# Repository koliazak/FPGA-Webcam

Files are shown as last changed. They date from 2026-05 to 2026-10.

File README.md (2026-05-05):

# Zynq-7010 Vision



This repository contains the source code, hardware design, and documentation for an edge computer vision project based on the Xilinx Zynq-7010 SoC (EBAZ4205 board). 

The goal of this project is to build a hardware-accelerated **Stereo Camera System** capable of capturing frames, detecting objects, and estimating depth. The project is divided into phases, starting with a single-camera streaming pipeline and scaling up to dual-camera stereo vision.

## Technical Specification & Project Roadmap

The development is divided into three main phases to ensure iterative progress of the Hardware/Software (HW/SW) partitioning.

### Phase 1: Minimum Viable Product (Capture & Web Streaming)

- **Goal:** Establish a reliable image capture pipeline and stream the video to a web interface.
- **Tasks:**
  - Implement mowdule in PL (FPGA) to configure the OV7670 registers.
  - Develop a pixel capture module to receive parallel data from the camera and convert it to an AXI-Stream.
  - Use DMA to write frames to DDR memory.
  - Implement a lightweight web server on the PS (ARM processor) running Petalinux to stream the frames.

### Phase 2: Hardware-Accelerated Image Processing
- **Goal:** Offload image basic computer vision tasks to the FPGA fabric.
- **Features to implement:**
  * Image enhancement (brightness/contrast adjustment, color space conversion).
  * Video stabilization.
  * Background removal / masking.
  * Basic face tracking using hardware-accelerated algorithms.

### Phase 3: Stereo Vision & Depth Estimation
- **Goal:** Synchronous capture from two cameras to calculate object distance.

## Hardware/Software Partitioning (Co-Design)

One of the core research aspects of this project is determining the optimal boundary between Programmable Logic (PL) and the Processing System (PS). 

- **Programmable Logic (FPGA):** Will handle deterministic, high-throughput operations (data ingestion, AXI-Stream conversions, low-level image processing, edge detection).
- **Processing System (ARM Core):** Will handle high-level application logic, web server, and complex CV inferences that are too heavy for the chip's logic fabric.

*(Note: The exact partitioning will be updated as experiments are conducted and performance bottlenecks are analyzed).*

## Tools & Technologies
- **HDL:** SystemVerilog / Verilog
- **Synthesis & Implementation:** Xilinx Vivado
- **Hardware:**
  - EBAZ4205 board
  - extension board 
  - 2x OV7670 camera module without FIFO

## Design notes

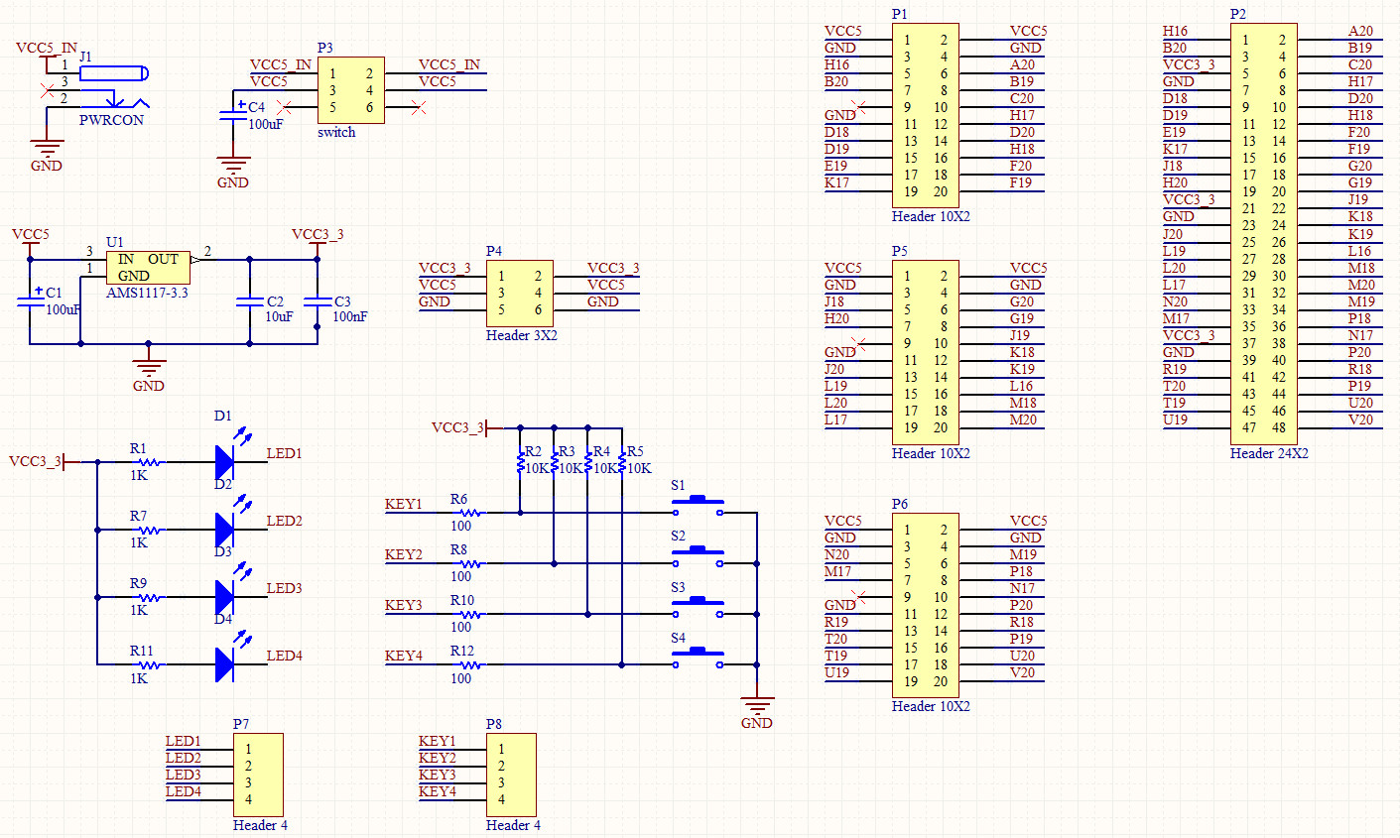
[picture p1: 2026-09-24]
docs/extension-board.jpg

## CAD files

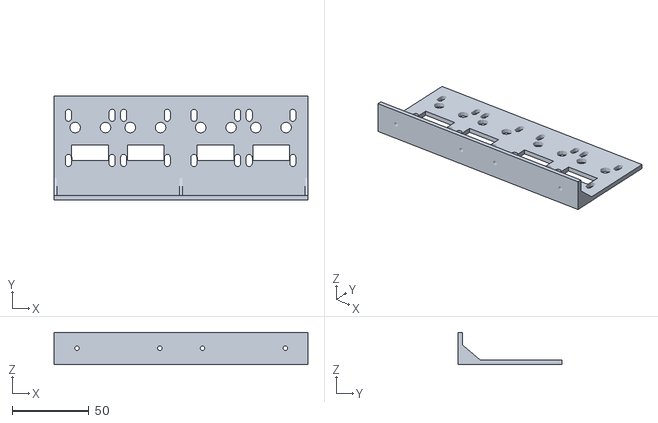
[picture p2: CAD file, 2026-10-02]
docs/CameraHolder.stl
165.9 x 68.0 x 20.9

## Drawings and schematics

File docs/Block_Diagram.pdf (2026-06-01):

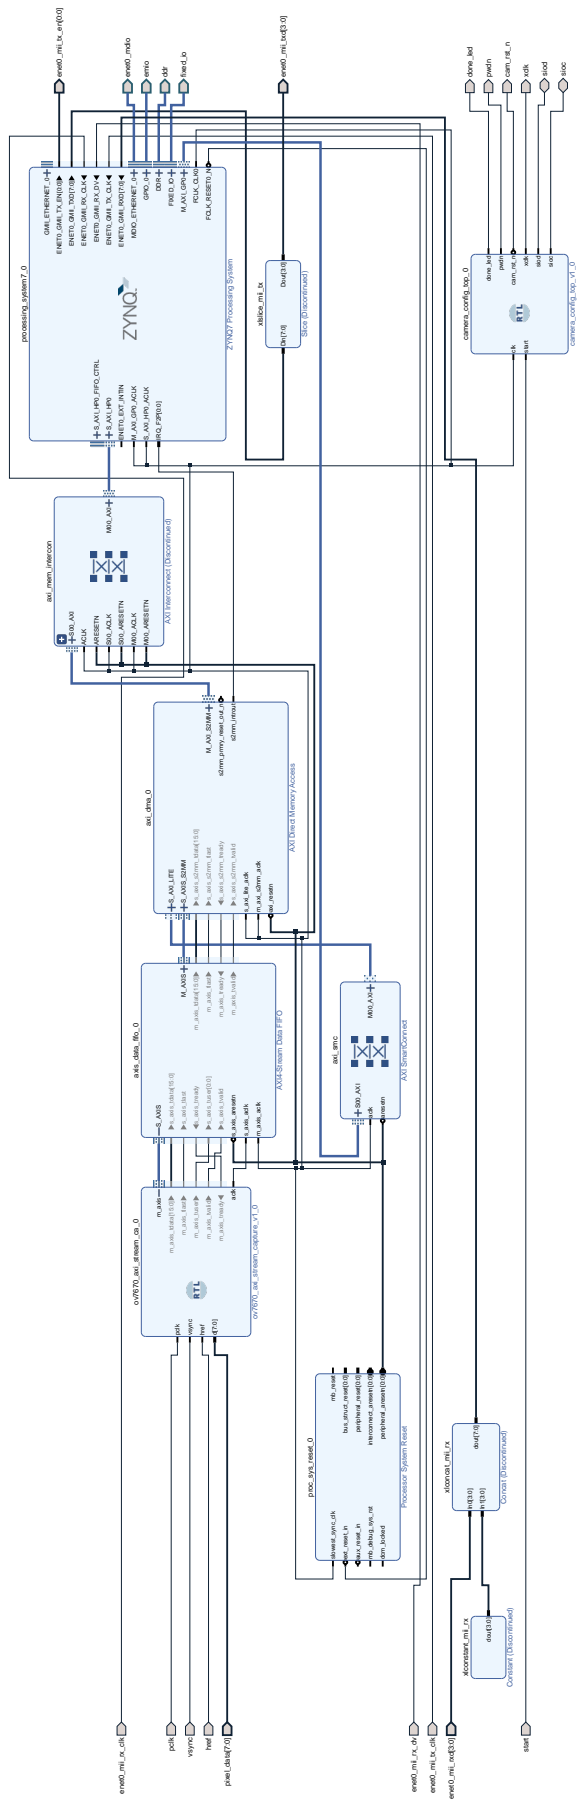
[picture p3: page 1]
axi_dma_0; S_AXI_LITE; M_AXI_S2MM; S_AXIS_S2MM; s_axis_s2mm_tdata[15:0]; s_axis_s2mm_tlast; s_axis_s2mm_tready; s_axis_s2mm_tvalid; s_axi_lite_aclk m_axi_s2mm_aclk; axi_resetn; s2mm_prmry_reset_out_n; s2mm_introut; axi_mem_intercon; S00_AXI; M00_AXI; ACLK; ARESETN; S00_ACLK; S00_ARESETN M00_ACLK M00_ARESETN; axi_smc; AXI SmartConnect; S00_AXI M00_AXI aclk; aresetn; axis_data_fifo_0; S_AXIS; s_axis_tdata[15:0]; s_axis_tlast; s_axis_tready; s_axis_tuser[0:0]; s_axis_tvalid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

AXI Interconnect (Discontinued)

AXI Direct Memory Access

AXI4-Stream Data FIFO

Processor System Reset

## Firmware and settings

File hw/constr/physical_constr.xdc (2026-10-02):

######################################################################
#                                                                    #
#           Constriants File for EBAZ4205 Zynq Board                 #
#                      v0.1 2019-12-08                               #
#             By Xiaohai Li (haixiaolee@gmail.com)                   #
#                                                                    #
######################################################################


# Dual-color LED
set_property IOSTANDARD LVCMOS33 [get_ports {emio_tri_io[1]}]
set_property IOSTANDARD LVCMOS33 [get_ports {emio_tri_io[0]}]

set_property PACKAGE_PIN W13 [get_ports {emio_tri_io[0]}]
set_property PACKAGE_PIN W14 [get_ports {emio_tri_io[1]}]

set_property DRIVE 12 [get_ports {emio_tri_io[1]}]
set_property DRIVE 12 [get_ports {emio_tri_io[0]}]

# ENET0 MII via EMIO
set_property IOSTANDARD LVCMOS33 [get_ports enet0_mdio_mdc]
set_property IOSTANDARD LVCMOS33 [get_ports enet0_mdio_mdio_io]

set_property IOSTANDARD LVCMOS33 [get_ports enet0_mii_rx_clk]
set_property IOSTANDARD LVCMOS33 [get_ports enet0_mii_rx_dv]
set_property IOSTANDARD LVCMOS33 [get_ports {enet0_mii_rxd[3]}]
set_property IOSTANDARD LVCMOS33 [get_ports {enet0_mii_rxd[2]}]
set_property IOSTANDARD LVCMOS33 [get_ports {enet0_mii_rxd[1]}]
set_property IOSTANDARD LVCMOS33 [get_ports {enet0_mii_rxd[0]}]

set_property IOSTANDARD LVCMOS33 [get_ports enet0_mii_tx_clk]
set_property IOSTANDARD LVCMOS33 [get_ports {enet0_mii_tx_en[0]}]
set_property IOSTANDARD LVCMOS33 [get_ports {enet0_mii_txd[3]}]
set_property IOSTANDARD LVCMOS33 [get_ports {enet0_mii_txd[2]}]
set_property IOSTANDARD LVCMOS33 [get_ports {enet0_mii_txd[1]}]
set_property IOSTANDARD LVCMOS33 [get_ports {enet0_mii_txd[0]}]

set_property PACKAGE_PIN W15 [get_ports enet0_mdio_mdc]
set_property PACKAGE_PIN Y14 [get_ports enet0_mdio_mdio_io]

set_property PACKAGE_PIN U14 [get_ports enet0_mii_rx_clk]
set_property PACKAGE_PIN W16 [get_ports enet0_mii_rx_dv]
set_property PACKAGE_PIN Y17 [get_ports {enet0_mii_rxd[3]}]
set_property PACKAGE_PIN V17 [get_ports {enet0_mii_rxd[2]}]
set_property PACKAGE_PIN V16 [get_ports {enet0_mii_rxd[1]}]
set_property PACKAGE_PIN Y16 [get_ports {enet0_mii_rxd[0]}]

set_property PACKAGE_PIN U15 [get_ports enet0_mii_tx_clk]
set_property PACKAGE_PIN W19 [get_ports {enet0_mii_tx_en[0]}]
set_property PACKAGE_PIN Y19 [get_ports {enet0_mii_txd[3]}]
set_property PACKAGE_PIN V18 [get_ports {enet0_mii_txd[2]}]
set_property PACKAGE_PIN Y18 [get_ports {enet0_mii_txd[1]}]
set_property PACKAGE_PIN W18 [get_ports {enet0_mii_txd[0]}]

set_property DRIVE 8 [get_ports enet0_mdio_mdc]
set_property DRIVE 8 [get_ports enet0_mdio_mdio_io]

set_property DRIVE 8 [get_ports {enet0_mii_tx_en[0]}]
set_property DRIVE 8 [get_ports {enet0_mii_txd[3]}]
set_property DRIVE 8 [get_ports {enet0_mii_txd[2]}]
set_property DRIVE 8 [get_ports {enet0_mii_txd[1]}]
set_property DRIVE 8 [get_ports {enet0_mii_txd[0]}]



#########################################################
#                                                       #
#                   CUSTOM PORTS                        #
#                                                       #
#########################################################

# Clock
#create_clock -period 20.000 -name clk [get_ports clk]
#set_property IOSTANDARD LVCMOS33 [get_ports clk]
#set_property PACKAGE_PIN N18 [get_ports clk]



# Left Camera

set_property IOSTANDARD LVCMOS33 [get_ports {pixel_data_l[7]}]
set_property IOSTANDARD LVCMOS33 [get_ports {pixel_data_l[6]}]
set_property IOSTANDARD LVCMOS33 [get_ports {pixel_data_l[5]}]
set_property IOSTANDARD LVCMOS33 [get_ports {pixel_data_l[4]}]
set_property IOSTANDARD LVCMOS33 [get_ports {pixel_data_l[3]}]
set_property IOSTANDARD LVCMOS33 [get_ports {pixel_data_l[2]}]
set_property IOSTANDARD LVCMOS33 [get_ports {pixel_data_l[1]}]
set_property IOSTANDARD LVCMOS33 [get_ports {pixel_data_l[0]}]

set_property PACKAGE_PIN T19 [get_ports {pixel_data_l[7]}]
set_property PACKAGE_PIN H16 [get_ports {pixel_data_l[6]}]
set_property PACKAGE_PIN U20 [get_ports {pixel_data_l[5]}]
set_property PACKAGE_PIN H18 [get_ports {pixel_data_l[4]}]
set_property PACKAGE_PIN V20 [get_ports {pixel_data_l[3]}]
set_property PACKAGE_PIN R18 [get_ports {pixel_data_l[2]}]
set_property PACKAGE_PIN U19 [get_ports {pixel_data_l[1]}]
set_property PACKAGE_PIN G20 [get_ports {pixel_data_l[0]}]


set_property IOSTANDARD LVCMOS33 [get_ports pclk_l]
create_clock -period 40.000 -name pclk_l [get_ports pclk_l]
set_property PACKAGE_PIN K17 [get_ports pclk_l]


set_property IOSTANDARD LVCMOS33 [get_ports xclk_l]
set_property IOSTANDARD LVCMOS33 [get_ports vsync_l]
set_property IOSTANDARD LVCMOS33 [get_ports href_l]
#set_property IOSTANDARD LVCMOS33 [get_ports pwdn_l]
#set_property IOSTANDARD LVCMOS33 [get_ports cam_rst_n_l]
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

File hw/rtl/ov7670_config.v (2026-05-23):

`timescale 1ns / 1ps

module ov7670_config (
    input wire clk,
    input wire rst_n,
    input wire start,          // active low (pulled-up btn)
    output reg done,


    output reg [6:0] s_axis_cmd_address,
    output reg       s_axis_cmd_start,
    output reg       s_axis_cmd_write,
    output reg       s_axis_cmd_write_multiple,
    output reg       s_axis_cmd_read,
    output reg       s_axis_cmd_stop,
    output reg       s_axis_cmd_valid,
    input  wire      s_axis_cmd_ready,


    output reg [7:0] s_axis_data_tdata,
    output reg       s_axis_data_tvalid,
    input  wire      s_axis_data_tready,
    output reg       s_axis_data_tlast,

    input wire i2c_busy,
    input wire i2c_missed_ack, // ignored for SCCB

    output reg pwdn,
    output reg cam_rst_n
);

    // -----------------------------------------------------------------
    // Configuration ROM
    //   High byte = OV7670 register address
    //   Low  byte = register value
    //   FFFF      = end of configuration
    //   FFF0      = delay marker
    // -----------------------------------------------------------------
    localparam ROM_DEPTH = 76;
    reg [15:0] rom [0:ROM_DEPTH-1];

    initial begin
        rom[0]  = 16'h1280;
        rom[1]  = 16'hFFF0;
        rom[2]  = 16'h1204;
        rom[3]  = 16'h1180;
        rom[4]  = 16'h0C00;
        rom[5]  = 16'h3E00;
        rom[6]  = 16'h0400;
        rom[7]  = 16'h40D0;
        rom[8]  = 16'h3A04;
        rom[9]  = 16'h1418;
        rom[10] = 16'h4FB3;
        rom[11] = 16'h50B3;
        rom[12] = 16'h5100;
        rom[13] = 16'h523D;
        rom[14] = 16'h53A7;
        rom[15] = 16'h54E4;
        rom[16] = 16'h589E;
        rom[17] = 16'h3DC0;
        rom[18] = 16'h1714;
        rom[19] = 16'h1802;
        rom[20] = 16'h3280;
        rom[21] = 16'h1903;
        rom[22] = 16'h1A7B;
        rom[23] = 16'h030A;
        rom[24] = 16'h0F41;
        rom[25] = 16'h1E00;
        rom[26] = 16'h330B;
        rom[27] = 16'h3C78;
        rom[28] = 16'h6900;
        rom[29] = 16'h7400;
        rom[30] = 16'hB084;
        rom[31] = 16'hB10C;
        rom[32] = 16'hB20E;
        rom[33] = 16'hB380;
        rom[34] = 16'h703A;
        rom[35] = 16'h7135;
        rom[36] = 16'h7211;
        rom[37] = 16'h73F0;
        rom[38] = 16'hA202;
        rom[39] = 16'h7A20;
        rom[40] = 16'h7B10;
        rom[41] = 16'h7C1E;
        rom[42] = 16'h7D35;
        rom[43] = 16'h7E5A;
        rom[44] = 16'h7F69;
        rom[45] = 16'h8076;
        rom[46] = 16'h8180;
        rom[47] = 16'h8288;
        rom[48] = 16'h838F;
        rom[49] = 16'h8496;
        rom[50] = 16'h85A3;
        rom[51] = 16'h86AF;
        rom[52] = 16'h87C4;
        rom[53] = 16'h88D7;
        rom[54] = 16'h89E8;
        rom[55] = 16'h13E0;
        rom[56] = 16'h0000;
        rom[57] = 16'h1000;
        rom[58] = 16'h0D40;
        rom[59] = 16'h1418;
        rom[60] = 16'hA505;
        rom[61] = 16'hAB07;
        rom[62] = 16'h2495;
        rom[63] = 16'h2533;
        rom[64] = 16'h26E3;
        rom[65] = 16'h9F78;
        rom[66] = 16'hA068;
        rom[67] = 16'hA103;
        rom[68] = 16'hA6D8;
        rom[69] = 16'hA7D8;
        rom[70] = 16'hA8F0;
        rom[71] = 16'hA990;
        rom[72] = 16'hAA94;
        rom[73] = 16'h13E5;
        rom[74] = 16'hFFFF;
    end


    reg [19:0] timer;

    localparam [3:0]
        ST_IDLE           = 4'd0,
        ST_PWRDN_RELEASE  = 4'd1,
        ST_RESET_WAIT     = 4'd2,
        ST_POST_RESET     = 4'd3,
        ST_READ_ROM       = 4'd4,
        ST_CHECK_ENTRY    = 4'd5,
        ST_DELAY          = 4'd6,
        ST_SEND_CMD       = 4'd7,
        ST_SEND_DATA0     = 4'd8,
        ST_SEND_DATA1     = 4'd9,
        ST_WAIT_I2C       = 4'd10,
        ST_DONE           = 4'd11;

    reg [3:0] state;
    reg [6:0] rom_addr;
    reg [15:0] rom_data;
    reg [7:0] reg_addr;
    reg [7:0] reg_val;
    reg       start_d;      // for edge detect

    always @(posedge clk or negedge rst_n) begin
        if (!rst_n) begin
            state  <= ST_IDLE;
            done   <= 1'b0;
            pwdn   <= 1'b1;      // power-down active high
            cam_rst_n <= 1'b0;   // reset active low

            rom_addr  <= 7'd0;
            rom_data  <= 16'd0;
            reg_addr  <= 8'd0;
            reg_val   <= 8'd0;
            timer     <= 20'd0;
            start_d   <= 1'b1;

            s_axis_cmd_address      <= 7'd0;
            s_axis_cmd_start        <= 1'b0;
            s_axis_cmd_write        <= 1'b0;
            s_axis_cmd_write_multiple <= 1'b0;
            s_axis_cmd_read         <= 1'b0;
            s_axis_cmd_stop         <= 1'b0;
            s_axis_cmd_valid        <= 1'b0;

            s_axis_data_tdata  <= 8'd0;
            s_axis_data_tvalid <= 1'b0;
            s_axis_data_tlast  <= 1'b0;
        end else begin
        
            s_axis_cmd_valid   <= 1'b0;
            s_axis_data_tvalid <= 1'b0;
            s_axis_data_tlast  <= 1'b0;

            start_d <= start;
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

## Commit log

2026-05-04 add datasheets for board and camera module
2026-05-23 add .dtsi file for petalinux to use UIO driver with DMA; program to capture video frames
2026-06-01 working version of camera stream via web
2026-06-12 add board-side streaming with cloud detection
2026-06-13 feat: working cloud-based object detection stream
    - Add FPS counters for encoder, detector, and stream
    - Add cloud connection status and retry logic
    - Fix FPS counter, shared-state, and shutdown
    - Working camera -> cloud -> stream pipeline
2026-09-24 change extension board, connect 2 cameras simultaneously
2026-10-02 add diff_stream.py to detect differences between the left and righ frames
2026-10-02 add model for camera modules
    [CameraHolder.stl]
2026-10-18 change camera configuration to YUYV output | add Sobel to diff_stream
2026-11-01 refactor(sw): restructure apps into board, pc, and common directories.
    Put stereo processing logic into common/stereo_core.py. Add pc_stereo_viewer.py for visualization.
